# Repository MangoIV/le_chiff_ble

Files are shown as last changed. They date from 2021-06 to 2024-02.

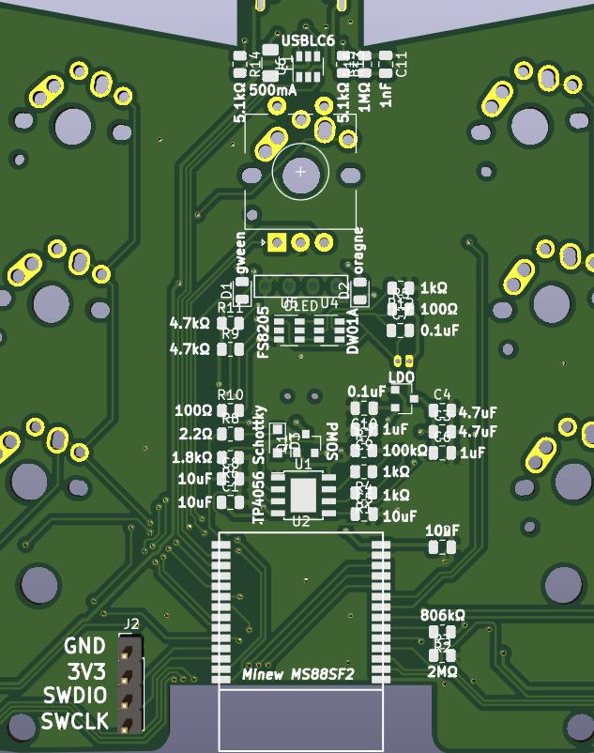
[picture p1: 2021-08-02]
resources/screenshots/mcu_area_soldering_help.png

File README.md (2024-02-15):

# le_chiff_ble
## What is this? 
This is a drop-in replacement PCB for [tominabox1's](https://github.com/tominabox1) Le Chiffre keyboard, one of my all time favourite boards. I redesigned the existing PCB from top up and added bluetooth. 
Please be so kind and check out the [original repo](https://github.com/tominabox1/Le-Chiffre-Keyboard) and leave a star. This is where you can also find case files for this PCB. 

Some of the footprints are not taken from the standard kicad libraries, huge thanks to [foostan](https://github.com/foostan) for making the awesome "kbd" library and to [ai03](https://ai03.com/) for their super nice footprint libraries, the minew symbol and footprints are by [oreore](https://github.com/ogatatsu).

All graphics on my PCB are hand drawn and belong to no-one but me. 

There are two PCBs in this repo one
- with hotswap, no silkscreen, see kicad/le_chiff_ble_hotswap
- without hotswap, with silkscreen, see kicad/le_chiff_ble

**I do not take any responsibility for what you do with the files supplied here in any way. Neither do I guarantee they're working for whatever purpose you intend ot use them.**

## State of the project
### implemented
- charging circuit is working
- MCU connects via bluetooth and USB
- all features have been tested and are working, including OLED and Encoder
- a working zmk firmware can be found [here](https://github.com/MangoIV/le_chiff_ble_config).
### open tasks
- the widgets in zmk for the OLED are still very basic, I'd like to do something to make them look better, this will be added after I finished and uploaded the firmware 
## How can I obtain one
- Gerbers are supplied, be free to order them from the PCB manufacturer you prefer.
### you will need parts: 
1. **Resistors, footprint is 0805:**
  - 1x 2M
  - 1x 1M
  - 1x 806k
  - 1x 100k
  - 2x 5.1k
  - 1x 1.8k 
  - 3x 1k
  - 2x 100
  - 1x 2.1
2. **Capacitors, footprint is 0805**
  - 4x 10uF
  - 2x 1uF
  - 2x 0.1uF
  - 1x 1nF
3. **Diodes**
  - 35x SOD123 for the switches and encoder
  - 1x Schottky, SOD323, should be low voltage drop
  - either 2x in switch LEDs or 2x 0805 SMD LEDs for the charging indicator
4. 1x PMOS, A03401A
5. 1x battery management chip, TP4056, footprint is SOP-8-PP
6. 1x LDO, XC6206PxxMR
7. 1x usblc6, footprint is sot-23-6
8. 1x 500mA Fuse, footprint is 1206/ 3216Metric
9. 1x battery protection IC DW01A, footprint is sot-23-6
10. 1x two nmos with gates connects FS8205, footprint is sot-23-6
11. 1x Minew MS88SF2, be careful to choose the version with nrF52840, there's also another version with the same name which won't work
12. 1x USB type c port, 12 pin
13. 1x MSK-12C02 smd toggle switch
14. 1x SW SPST TL3342 push switch for reset
15. 34-35 MX/alps/choc switches depending on whether you use the encoder or not
16. Battery connector with 1.25mm pitch, choose whichever you're fine with
17. optional: 1x Encoder, 1x 128x32 OLED
## How do I build one? 
- solder all components
- flash bootloader (I liked [this one](https://github.com/adafruit/Adafruit_nRF52_Bootloader) a lot, it's fairly easy to modify to your needs, e.g. the name the board will appear with in bootloader mode)
- plug into PC and test whether everything is working, flash Firmware 
- the firmware can be forked from [here](https://github.com/MangoIV/le_chiff_ble_config), just adjust the `.keymap` file, push, let GitHub Actions build it for you, download, done
- plug in battery, plug in PC again to unlock DW01A (this needs to be done everytime you physically disconnect the PCB from the battery)
- be careful to adjust resistor value of the tp4056 when you take different battery sizes, I chose 1Ah which works fine with the specified resistor values
- verify charging and bluetooth works 
- continue building as if this was a "normal" chiffre

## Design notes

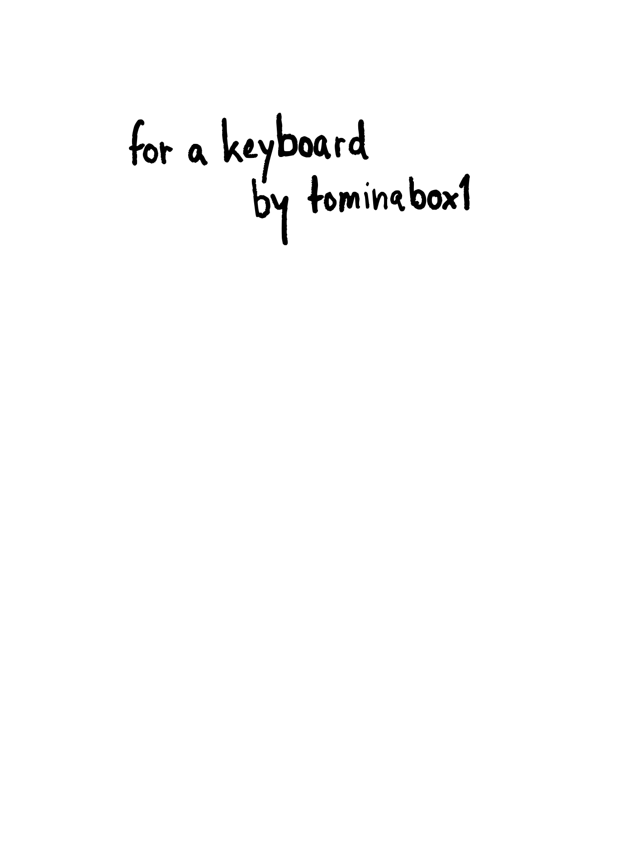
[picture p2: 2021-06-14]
graphics/tomina.png

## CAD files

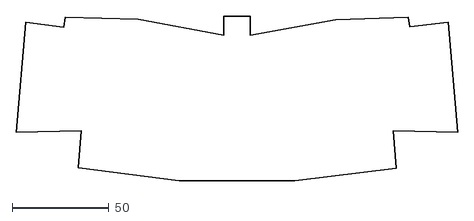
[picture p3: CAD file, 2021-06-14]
plots/dxf/LeChiffre-Edge_Cuts.dxf
228.4 x 85.0

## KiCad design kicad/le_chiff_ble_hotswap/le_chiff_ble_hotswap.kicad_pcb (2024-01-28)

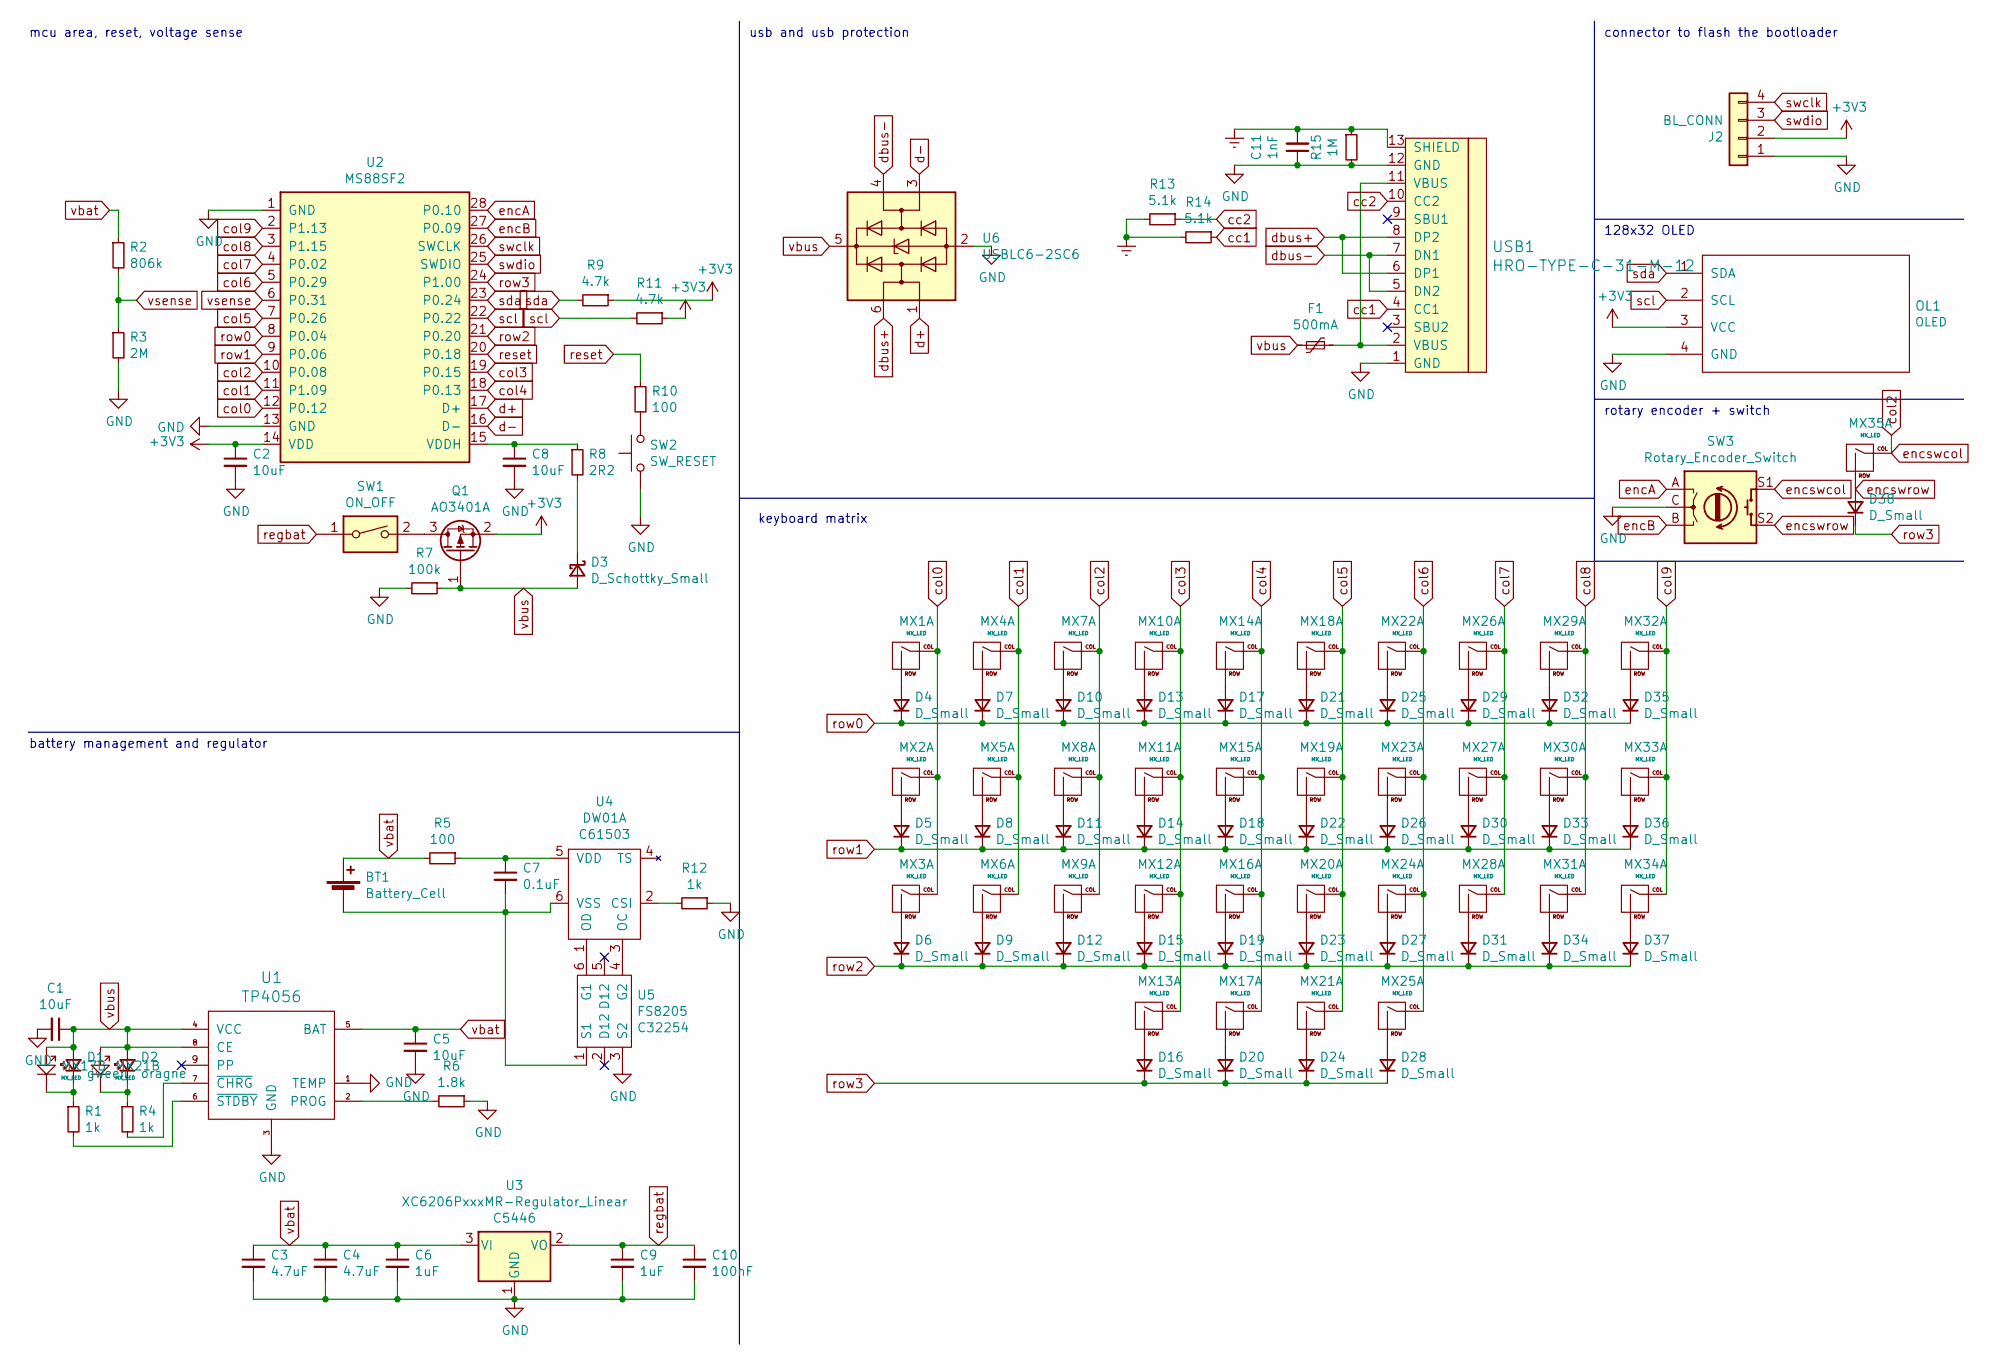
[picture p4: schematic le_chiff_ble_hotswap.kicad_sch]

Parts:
BT1: Battery_Cell; Molex_PicoBlade_53048-0210_1x02_P1.25mm_Horizontal
C1, C2, C5, C8: 10uF; C_0805_2012Metric
C3, C4: 4.7uF; C_0805_2012Metric
C6, C9: 1uF; C_0805_2012Metric
C7: 0.1uF; C_0805_2012Metric
C10: 100nF; C_0805_2012Metric
C11: 1nF; C_0805_2012Metric
D1: gween; D_0805_2012Metric
D2: oragne; D_0805_2012Metric
D3: D_Schottky_Small; D_SOD-323_HandSoldering
D4, D5, D6, D7, D8, D9, D10, D11, D12, D13, D14, D15, D16, D17, D18, D19, D20, D21, D22, D23, D24, D25, D26, D27, D28, D29, D30, D31, D32, D33, D34, D35, D36, D37, D38: D_Small; D_SOD-123
F1: 500mA; Fuse_1206_3216Metric
J2: BL_CONN; PinHeader_1x04_P2.54mm_Vertical
MX1, MX2, MX3, MX4, MX5, MX6, MX7, MX8, MX9, MX10, MX11, MX12, MX13, MX14, MX15, MX16, MX18, MX19, MX20, MX22, MX23, MX24, MX25, MX26, MX27, MX28, MX29, MX30, MX31, MX32, MX33, MX34, MX35: MX_LED; MX-Alps-Choc-1U-NoLED
MX17, MX21: MX_LED; MX-Alps-Choc-2U-StabFlip
OL1: OLED; OLED_1side
Q1: AO3401A; SOT-23
R1, R4, R12: 1k; R_0805_2012Metric
R2: 806k; R_0805_2012Metric
R3: 2M; R_0805_2012Metric
R5, R10: 100; R_0805_2012Metric
R6: 1.8k; R_0805_2012Metric
R7: 100k; R_0805_2012Metric
R8: 2R2; R_0805_2012Metric
R9, R11: 4.7k; R_0805_2012Metric
R13, R14: 5.1k; R_0805_2012Metric
R15: 1M; R_0805_2012Metric
SW1: ON_OFF; switch_MSK-12C02_smd
SW2: SW_RESET; SW_SPST_TL3342
SW3: Rotary_Encoder_Switch; RotaryEncoder_EC11-no-legs
U1: TP4056; TP4056_SOP-8-PP
U2: MS88SF2; MINEW_MS88SF2
U3: XC6206PxxxMR-Regulator_Linear; SOT-23; LCSC C5446
U4: DW01A; SOT-23-6; LCSC C61503
U5: FS8205; SOT-23-6; LCSC C32254
U6: USBLC6-2SC6; SOT-23-6
USB1: HRO-TYPE-C-31-M-12; HRO-TYPE-C-31-M-12-Assembly

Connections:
+3V3: C2.1, J2.2, OL1.3 (VCC), Q1.2 (S), R9.1, R11.1, U2.14 (VDD)
Earth: C11.2, R13.2, R14.2, R15.1, USB1.13 (SHIELD)
GND: C1.2, C2.2, C3.2, C4.2, C5.2, C6.2, C8.2, C9.2, C10.2, C11.1, J2.1, OL1.4 (GND), R3.2, R6.1, R7.2, R12.1, R15.2, SW2.1, SW3.C, U1.1 (TEMP), U1.3 (GND), U2.1 (GND), U2.13 (GND), U3.1 (GND), U5.3 (S2), U6.2 (GND), USB1.1 (GND), USB1.12 (GND)
unnamed: BT1.2 (-), C7.2, U4.6 (VSS), U5.1 (S1)
unnamed: C7.1, R5.1, U4.5 (VDD)
unnamed: C8.1, R8.1, U2.15 (VDDH)
unnamed: D1.1 (K), MX17.4 (C), R1.1
unnamed: D2.1 (K), MX21.4 (C), R4.1
unnamed: D3.1 (K), R8.2
unnamed: D4.2 (A), MX1.2 (ROW)
unnamed: D5.2 (A), MX2.2 (ROW)
unnamed: D6.2 (A), MX3.2 (ROW)
unnamed: D7.2 (A), MX4.2 (ROW)
unnamed: D8.2 (A), MX5.2 (ROW)
unnamed: D9.2 (A), MX6.2 (ROW)
unnamed: D10.2 (A), MX7.2 (ROW)
unnamed: D11.2 (A), MX8.2 (ROW)
unnamed: D12.2 (A), MX9.2 (ROW)
unnamed: D13.2 (A), MX10.2 (ROW)
unnamed: D14.2 (A), MX11.2 (ROW)
unnamed: D15.2 (A), MX12.2 (ROW)
unnamed: D16.2 (A), MX13.2 (ROW)
unnamed: D17.2 (A), MX14.2 (ROW)
unnamed: D18.2 (A), MX15.2 (ROW)
unnamed: D19.2 (A), MX16.2 (ROW)
unnamed: D20.2 (A), MX17.2 (ROW)
unnamed: D21.2 (A), MX18.2 (ROW)
unnamed: D22.2 (A), MX19.2 (ROW)
unnamed: D23.2 (A), MX20.2 (ROW)
unnamed: D24.2 (A), MX21.2 (ROW)
unnamed: D25.2 (A), MX22.2 (ROW)
unnamed: D26.2 (A), MX23.2 (ROW)
unnamed: D27.2 (A), MX24.2 (ROW)
unnamed: D28.2 (A), MX25.2 (ROW)
unnamed: D29.2 (A), MX26.2 (ROW)
unnamed: D30.2 (A), MX27.2 (ROW)
unnamed: D31.2 (A), MX28.2 (ROW)
unnamed: D32.2 (A), MX29.2 (ROW)
unnamed: D33.2 (A), MX30.2 (ROW)
unnamed: D34.2 (A), MX31.2 (ROW)
unnamed: D35.2 (A), MX32.2 (ROW)
unnamed: D36.2 (A), MX33.2 (ROW)
unnamed: D37.2 (A), MX34.2 (ROW)
unnamed: F1.1, USB1.2 (VBUS), USB1.11 (VBUS)
unnamed: Q1.3 (D), SW1.2
unnamed: R1.2, U1.6 (~STDBY)
unnamed: R4.2, U1.7 (~CHRG)
unnamed: R6.2, U1.2 (PROG)
unnamed: R10.2, SW2.2
unnamed: R12.2, U4.2 (CSI)
unnamed: U4.1 (OD), U5.6 (G1)
unnamed: U4.3 (OC), U5.4 (G2)
cc1: R14.1, USB1.4 (CC1)
cc2: R13.1, USB1.10 (CC2)
col0: MX1.1 (COL), MX2.1 (COL), MX3.1 (COL), U2.12 (P0.12)
col1: MX4.1 (COL), MX5.1 (COL), MX6.1 (COL), U2.11 (P1.09)
col2: MX7.1 (COL), MX8.1 (COL), MX9.1 (COL), MX35.1 (COL), SW3.S1, U2.10 (P0.08)
col3: MX10.1 (COL), MX11.1 (COL), MX12.1 (COL), MX13.1 (COL), U2.19 (P0.15)
col4: MX14.1 (COL), MX15.1 (COL), MX16.1 (COL), MX17.1 (COL), U2.18 (P0.13)
col5: MX18.1 (COL), MX19.1 (COL), MX20.1 (COL), MX21.1 (COL), U2.7 (P0.26)
col6: MX22.1 (COL), MX23.1 (COL), MX24.1 (COL), MX25.1 (COL), U2.5 (P0.29)
col7: MX26.1 (COL), MX27.1 (COL), MX28.1 (COL), U2.4 (P0.02)
col8: MX29.1 (COL), MX30.1 (COL), MX31.1 (COL), U2.3 (P1.15)
col9: MX32.1 (COL), MX33.1 (COL), MX34.1 (COL), U2.2 (P1.13)
d+: U2.17 (D+), U6.1 (I/O1)
d-: U2.16 (D-), U6.3 (I/O2)
dbus+: U6.6 (I/O1), USB1.6 (DP1), USB1.8 (DP2)
dbus-: U6.4 (I/O2), USB1.5 (DN2), USB1.7 (DN1)
encA: SW3.A, U2.28 (P0.10)
encB: SW3.B, U2.27 (P0.09)
encswrow: D38.2 (A), MX35.2 (ROW), SW3.S2
regbat: C9.1, C10.1, SW1.1, U3.2 (VO)
reset: R10.1, U2.20 (P0.18)
row0: D4.1 (K), D7.1 (K), D10.1 (K), D13.1 (K), D17.1 (K), D21.1 (K), D25.1 (K), D29.1 (K), D32.1 (K), D35.1 (K), U2.8 (P0.04)
row1: D5.1 (K), D8.1 (K), D11.1 (K), D14.1 (K), D18.1 (K), D22.1 (K), D26.1 (K), D30.1 (K), D33.1 (K), D36.1 (K), U2.9 (P0.06)
row2: D6.1 (K), D9.1 (K), D12.1 (K), D15.1 (K), D19.1 (K), D23.1 (K), D27.1 (K), D31.1 (K), D34.1 (K), D37.1 (K), U2.21 (P0.20)
row3: D16.1 (K), D20.1 (K), D24.1 (K), D28.1 (K), D38.1 (K), U2.24 (P1.00)
scl: OL1.2 (SCL), R11.2, U2.22 (P0.22)
sda: OL1.1 (SDA), R9.2, U2.23 (P0.24)
swclk: J2.4, U2.26 (SWCLK)
swdio: J2.3, U2.25 (SWDIO)
vbat: BT1.1 (+), C3.1, C4.1, C5.1, C6.1, R2.1, R5.2, U1.5 (BAT), U3.3 (VI)
vbus: C1.1, D1.2 (A), D2.2 (A), D3.2 (A), F1.2, MX17.3 (A), MX21.3 (A), Q1.1 (G), R7.1, U1.4 (VCC), U1.8 (CE), U6.5 (VBUS)
vsense: R2.2, R3.1, U2.6 (P0.31)

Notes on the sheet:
mcu area, reset, voltage sense
keyboard matrix
battery management and regulator
128x32 OLED
usb and usb protection
rotary encoder + switch
connector to flash the bootloader

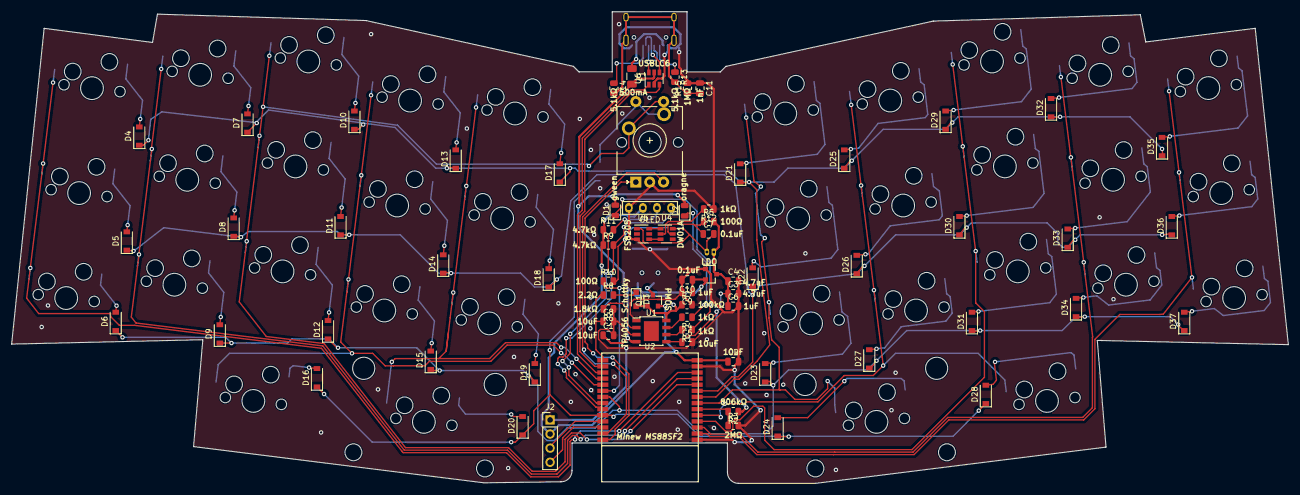
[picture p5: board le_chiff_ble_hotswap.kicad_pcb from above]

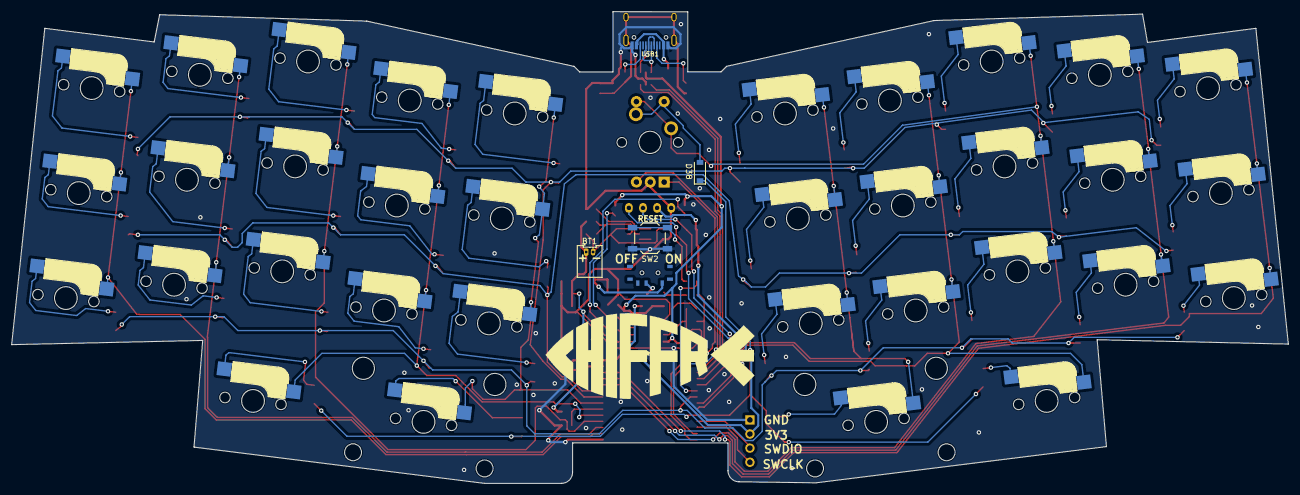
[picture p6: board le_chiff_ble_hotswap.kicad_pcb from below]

Board: 2 copper layers, 230.0 x 85.0 mm, 114 parts (5 on the bottom side), 84 nets.

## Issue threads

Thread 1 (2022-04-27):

This project has no license

maxhbr, 2022-04-27:
It might be worth to add one to make it actually (re)usable and Open Source.

MangoIV, 2022-04-28:
I haven't figured out a license yet, your request is valid but I think that for personal use not having a license it totally fine and for every retailer who actually wants to sell this I want to have personal communication anyway so in general I think it makes the most sense to keep it as is. If I find a license that makes sense for my use case then I'll add it. Also mind that with hardware it's generally a bit more complicated than with software (I'm no lawyer and I don't wanna contact one to figure our a license).

MangoIV, 2022-04-28:
I might make it gpl v3 to follow the original project although, again, I don't know whether I have to because I remade the whole board from scratch, it just fits the same case. again, I don't know whether this is even possible/necessary with hardware designs.

maxhbr, 2022-04-29:
> I think that for personal use not having a license it totally fine

sadly that is wrong, without an license no one is actually allowed to use. The default is no-rights.

GPL-3.0 sounds like the right choice, especially if you are building on top of stuff licensed under it. Otherwise https://choosealicense.com/ might be interesting.

Closed 2022-04-28.

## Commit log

2021-06-14 finished the schematics and the PCB, maybe some silkscreen to come..
    [LeChiffre-Edge_Cuts.dxf]
2021-06-14 saved and have to commit
    [le_chiff_ble.kicad_pcb]
2021-08-05 changed paths to be relative
    [le_chiff_ble.sch]
2024-01-28 added kicad project for hotswap board based on the work of weteor (#3)
    added kicad project for hotswap board based on the work of weteor
    [le_chiff_ble_hotswap.kicad_pcb, le_chiff_ble_hotswap.kicad_sch]
2024-02-15 [chore] update README to show the existance of the hotswap PCB (#4)
